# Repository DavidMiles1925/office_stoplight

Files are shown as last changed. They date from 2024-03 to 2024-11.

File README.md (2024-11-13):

# Office Stoplight

Stoplight GIF

## Project Decription

I work from home, and my workspace also happens to directly attatch to the garage. Because of this, my family often needs access to the garage, but does not know if I can be disturbed. This system will give them a definitive answer, by placing adjustable LEDs on the outside of the office and garage doors.

Please feel free to use everything here to build your own.

## Hardware

### Pre-requisites:

1. You will need to set up a Raspberry Pi. **[Click Here for Instructions](https://github.com/DavidMiles1925/pi_zero_setup)**

### Components List

NOTE: I used some larger LEDs for the "above door" unit, but that is optional.

| Item | Quantity | Link |
| --- | --- | --- |
| Raspberry Pi Zero | 1 | [Microcenter](https://www.microcenter.com/product/643085/raspberry-pi-zero-2-w) |
| Red LEDs | 2 | [Amazon](https://www.amazon.com/gp/product/B07QXR5MZB/ref=ppx_yo_dt_b_search_asin_title?ie=UTF8&psc=1) |
| Yellow LEDs | 2 | [Amazon](https://www.amazon.com/gp/product/B07QXR5MZB/ref=ppx_yo_dt_b_search_asin_title?ie=UTF8&psc=1) |
| Green LEDs | 2 | [Amazon](https://www.amazon.com/gp/product/B07QXR5MZB/ref=ppx_yo_dt_b_search_asin_title?ie=UTF8&psc=1) |
| BLue LED | 1 | [Amazon](https://www.amazon.com/gp/product/B07QXR5MZB/ref=ppx_yo_dt_b_search_asin_title?ie=UTF8&psc=1) |
| 1KΩ Resistors | 3 | [Amazon](https://www.amazon.com/gp/product/B07ZX2CB6B/ref=ppx_yo_dt_b_search_asin_title?ie=UTF8&psc=1) |
| 220Ω Resistors | 2 | [Amazon](https://www.amazon.com/gp/product/B07ZX2CB6B/ref=ppx_yo_dt_b_search_asin_title?ie=UTF8&psc=1) |
| 147Ω Resistors | 6 | [Amazon](https://www.amazon.com/gp/product/B07ZX2CB6B/ref=ppx_yo_dt_b_search_asin_title?ie=UTF8&psc=1) |
| 12mm Colored Buttons | 3 | [Amazon](https://www.amazon.com/gp/product/B075VBV4QH/ref=ppx_yo_dt_b_search_asin_title?ie=UTF8&psc=1) |
| Two-Prong Button | 1 | [Amazon](https://www.amazon.com/gp/product/B0827LX3FV/ref=ppx_yo_dt_b_search_asin_title?ie=UTF8&psc=1) |
| Wire | 25ft | [Amazon](https://www.amazon.com/gp/product/B0CFJY34GD/ref=ppx_yo_dt_b_search_asin_title?ie=UTF8&th=1)  |

### Circuit Diagram

This diagram represents the circuit for the "desk" unit. For the "door" unit, simply omit the buttons.

Use the table in the [Connections](#connections) section to connect the pins to the Pi's pins.

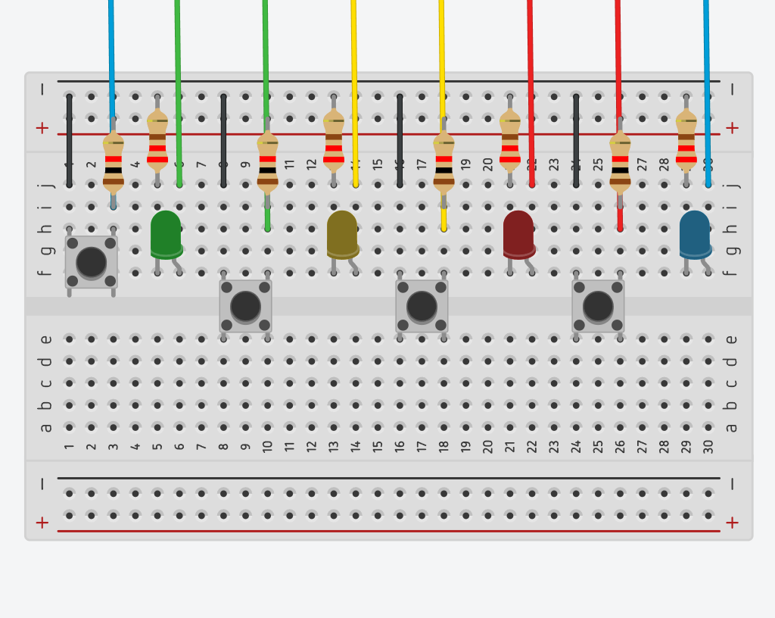
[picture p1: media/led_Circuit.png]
Diagram


### Resistor Values

**Value for buttons:** 1KΩ

**Value for Green and Yellow LEDs:** 147Ω

**Value for Red LEDs:** 220Ω

### Connections

| Purpose | Pin (BCM) |
| --- | --- |
| Power Indicator | 17 |
| Red LED - Desk | 5 |
| Red LED - Hall | 11 |
| Yellow LED - Desk | 6 |
| Yellow LED - Hall | 13 |
| Green LED - Desk | 26 |
| Green LED - Hall | 19 |
| Button - Lights OFF | 12 |
| Button - Red Light ON | 23 |
| Button - Yellow Light ON | 24 |
| Button - Green Light ON  | 25 |

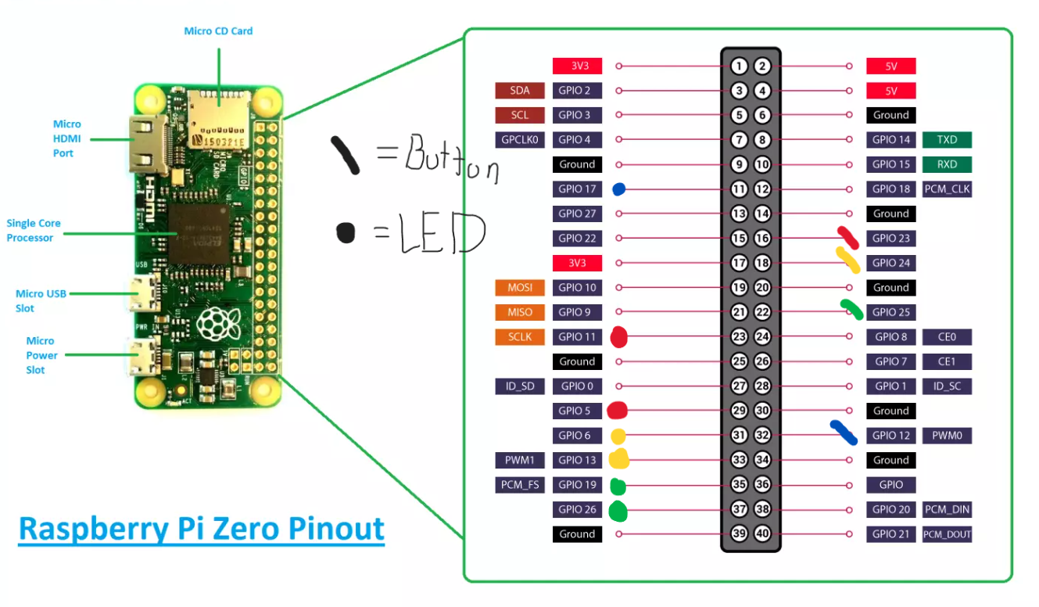
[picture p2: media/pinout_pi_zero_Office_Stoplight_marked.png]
Pi Diagram


## Running the Code

**1. Clone the Repo**

```bash
git clone https://github.com/DavidMiles1925/office_stoplight.git
```

**2. Navigate to Program Directory**

```bash
cd office_stoplight
```

**3. Test the program**

```bash
sudo python stoplight.py
```

**4. Set to Run on Startup**

```bash
sudo nano /etc/rc.local
```

**Add this to the file `rc.local`. _DO NOT FORGET THE "&"_**

```bash
sudo python /your_pi_name/office_stoplight/stoplight.py &
```

## What the Lights Mean

- **RED:** DO NOT DISTURB
- **YELLOW:** You can come in, but be quiet.
- **GREEN:** Come on in!

## Description and Gallery

**Prototying**

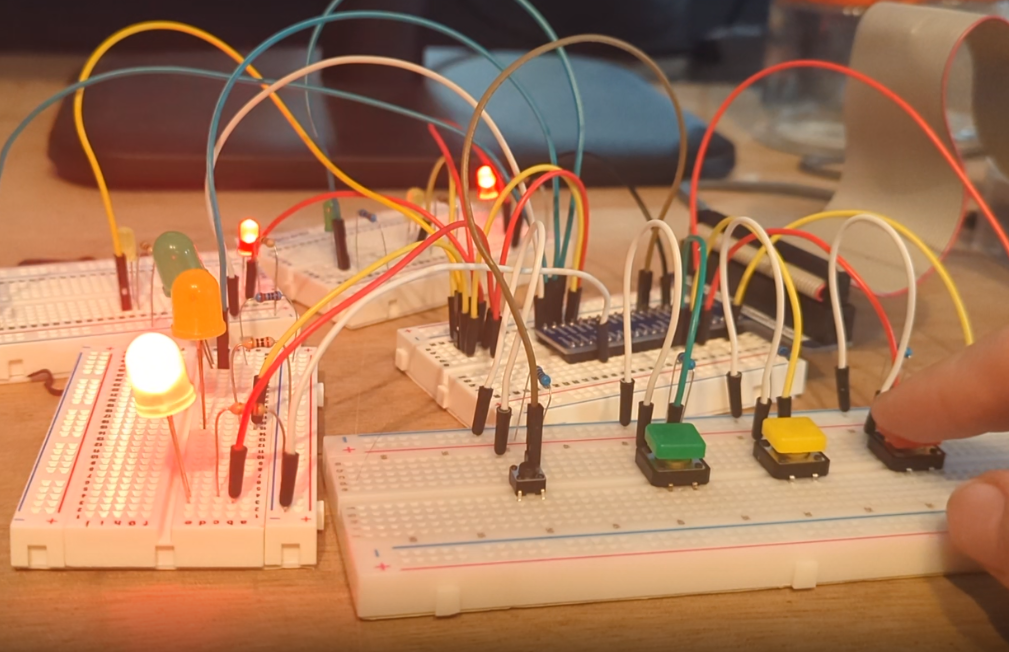
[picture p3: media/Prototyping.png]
Prototype

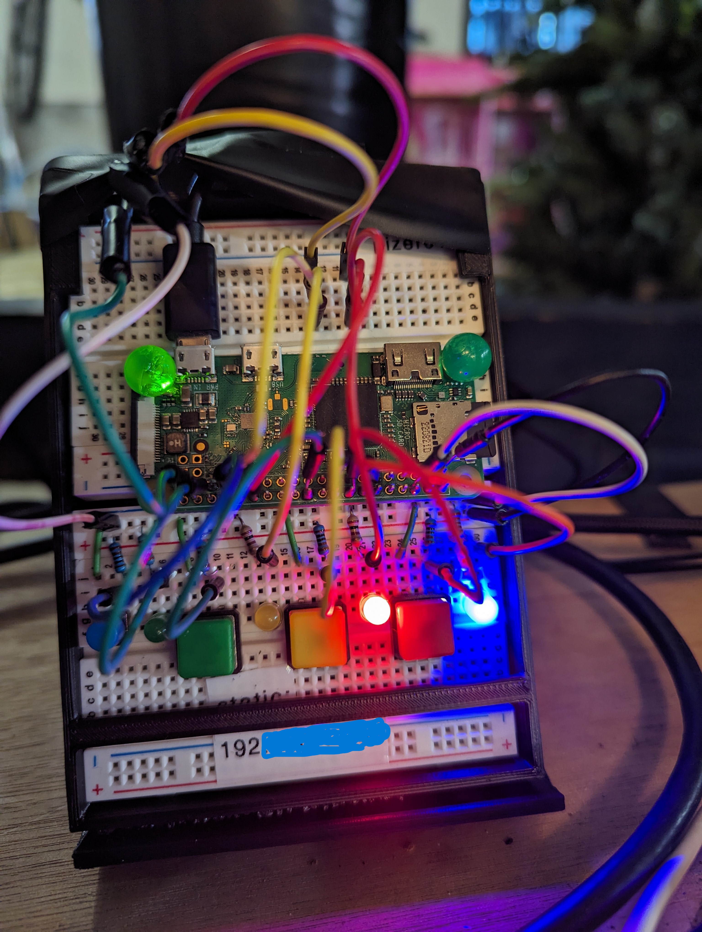
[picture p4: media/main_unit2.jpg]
Open


**Main Unit - Final**

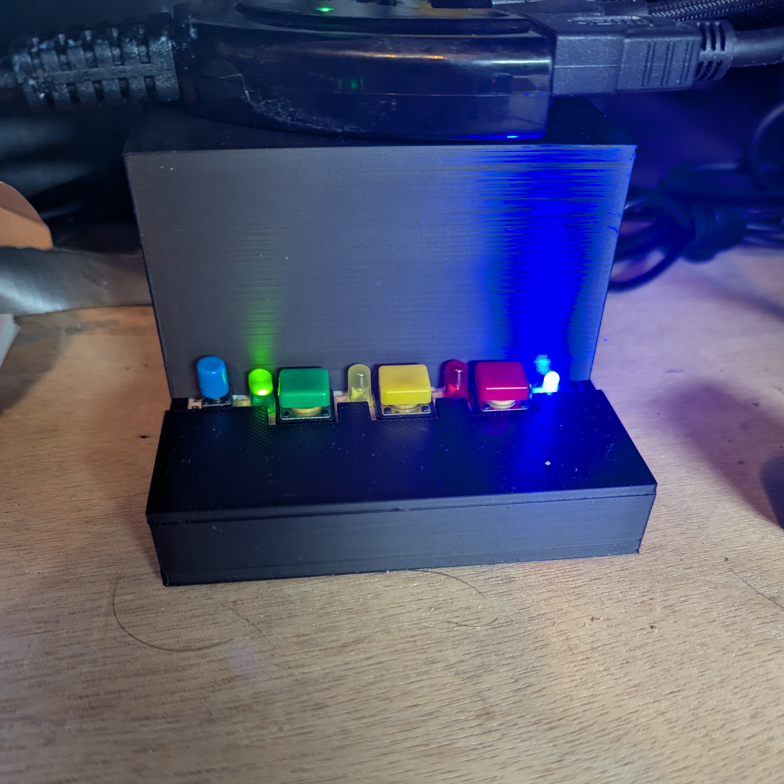
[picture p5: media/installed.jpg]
Main Unit


**Door Unit - Final**

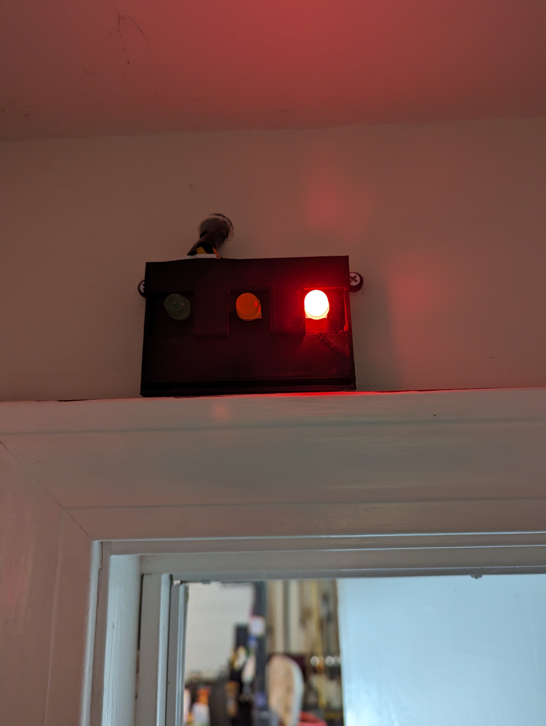
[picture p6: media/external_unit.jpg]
Door Unit


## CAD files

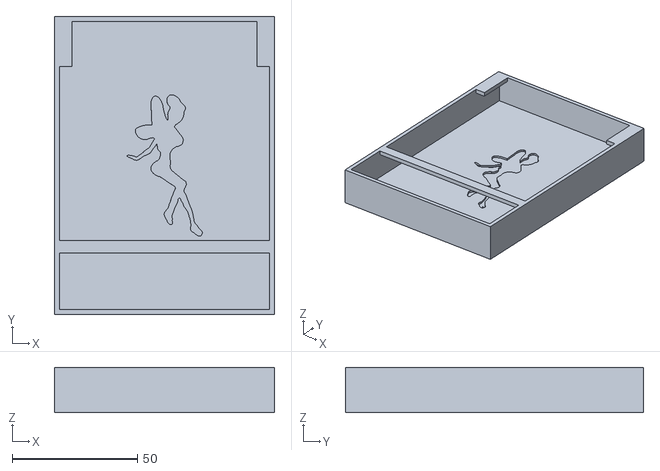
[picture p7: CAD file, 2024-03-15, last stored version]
3D Printable Models/Breadboard Holder for Main Unit.stl
88.0 x 119.0 x 18.0

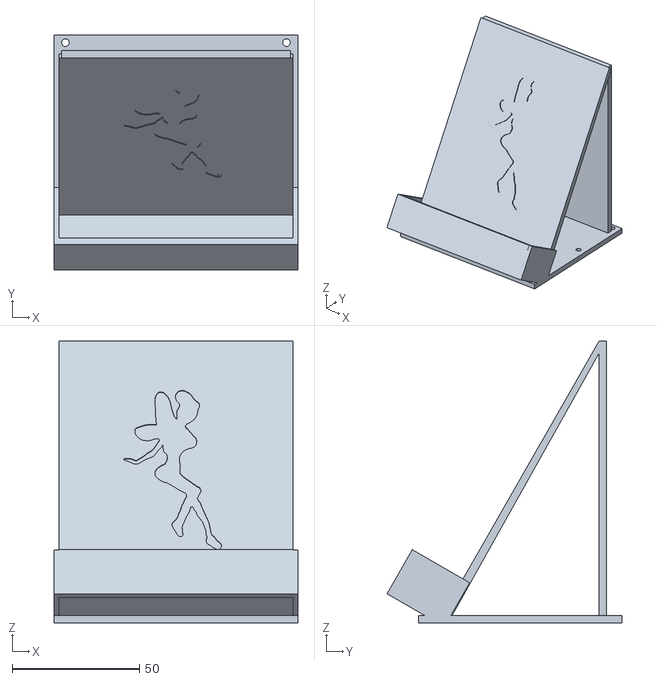
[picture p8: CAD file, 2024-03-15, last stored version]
3D Printable Models/Main Unit Stand.stl
96.0 x 92.5 x 111.0

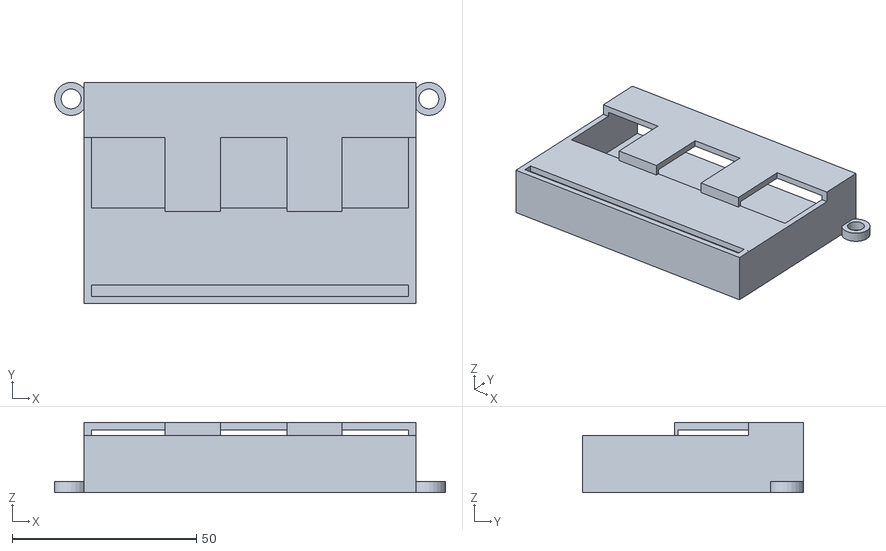
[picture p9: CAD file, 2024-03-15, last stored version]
3D Printable Models/External LED Holder.stl
106.0 x 60.0 x 19.0

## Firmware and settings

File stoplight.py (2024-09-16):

import RPi.GPIO as GPIO
from time import sleep

INDICATOR_LED_PIN = 17

RED1_LED_PIN = 5
RED2_LED_PIN = 11
YELLOW1_LED_PIN = 6
YELLOW2_LED_PIN = 13
GREEN1_LED_PIN = 26
GREEN2_LED_PIN = 19

BLUE_BUTTON_PIN = 12
RED_BUTTON_PIN = 23
YELLOW_BUTTON_PIN = 24
GREEN_BUTTON_PIN = 25

LED_PIN_ARRAY = [INDICATOR_LED_PIN, RED1_LED_PIN, RED2_LED_PIN, YELLOW1_LED_PIN, YELLOW2_LED_PIN, GREEN1_LED_PIN, GREEN2_LED_PIN]
BUTTON_PIN_ARRAY = [BLUE_BUTTON_PIN, RED_BUTTON_PIN, YELLOW_BUTTON_PIN, GREEN_BUTTON_PIN]

# This functions turns ALL LEDs "ON" or "OFF" depending on the status parameter

def all_leds(status):

    if status == "on" or status == "ON":
        for x in range(len(LED_PIN_ARRAY)):
            GPIO.output(LED_PIN_ARRAY[x], GPIO.HIGH)

    else:
        for x in range(len(LED_PIN_ARRAY)):
            GPIO.output(LED_PIN_ARRAY[x], GPIO.LOW)

    GPIO.output(INDICATOR_LED_PIN, GPIO.HIGH)



def led_on(pin):
    GPIO.output(pin, GPIO.HIGH)


def setup_pins():
    # Board Mode: BCM
    GPIO.setmode(GPIO.BCM)

    # Disable Warnings
    GPIO.setwarnings(False)

    for x in range(len(LED_PIN_ARRAY)):
        GPIO.setup(LED_PIN_ARRAY[x], GPIO.OUT)
        GPIO.output(LED_PIN_ARRAY[x], GPIO.LOW)
        print(f"Pin {LED_PIN_ARRAY[x]} enabled as output")

    for x in range(len(BUTTON_PIN_ARRAY)):
        GPIO.setup(BUTTON_PIN_ARRAY[x], GPIO.IN)
        print(f"Pin {BUTTON_PIN_ARRAY[x]} enabled as input")


def handle_error(e, msg):
    print(msg)
    print(f"Error: {e}")
    GPIO.cleanup()
    exit()


def check_buttons():
    try:
        if GPIO.input(RED_BUTTON_PIN) == False and GPIO.input(YELLOW_BUTTON_PIN) == False:
            light_show()


        if GPIO.input(BLUE_BUTTON_PIN) == False and GPIO.input(RED_BUTTON_PIN) == False:
            print("Blue and Red Buttons Pressed. Program Terminated.")
            print("DONE")
            GPIO.cleanup()
            exit()

            
        if GPIO.input(BLUE_BUTTON_PIN) == False:
            all_leds("off")
            print("OFF")
            sleep(0.2)

        elif GPIO.input(RED_BUTTON_PIN) == False:
            print("RED")
            all_leds("off")
            led_on(RED1_LED_PIN)
            led_on(RED2_LED_PIN)
            sleep(0.2)

        elif GPIO.input(YELLOW_BUTTON_PIN) == False:
            print("YELLOW")
            all_leds("off")
            led_on(YELLOW1_LED_PIN)
            led_on(YELLOW2_LED_PIN)
            sleep(0.2)

        elif GPIO.input(GREEN_BUTTON_PIN) == False:
            print(f"GREEN")
            all_leds("off")
            led_on(GREEN1_LED_PIN)
            led_on(GREEN2_LED_PIN)
            sleep(0.2)

    except Exception as e:
        handle_error(e, "The check_buttons function failed")


def light_show():
    try:
        print("Light show!")

        # lightshow_on = True
        lightshow_on = 0
        loop_sleep_time = 0.1

        all_leds("on")
        sleep(0.5)
        all_leds("off")

        while lightshow_on < 7:

            all_leds("off")
            led_on(RED1_LED_PIN)
            led_on(RED2_LED_PIN)
            sleep(loop_sleep_time)

            all_leds("off")
            led_on(YELLOW1_LED_PIN)
            led_on(YELLOW2_LED_PIN)
            sleep(loop_sleep_time)

            all_leds("off")
            led_on(GREEN1_LED_PIN)
            led_on(GREEN2_LED_PIN)
            sleep(loop_sleep_time)

            lightshow_on = lightshow_on + 1

        all_leds("off")
        led_on(RED1_LED_PIN)
        led_on(RED2_LED_PIN)

    except Exception as e:
        handle_error(e, "The light_show function failed")
    


if __name__ == "__main__":
    setup_pins()

    GPIO.output(INDICATOR_LED_PIN, GPIO.HIGH)

    light_show()

    try:
        while True:
            check_buttons()

    except Exception as e:
        handle_error(e, "The main function failed")

    except KeyboardInterrupt:
        print("Ctrl+C pressed. Program Terminated")
        GPIO.cleanup()
        exit()


        

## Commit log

2023-11-10 switch pins for zero port
2024-03-15 refactor and update readme
    [External LED Holder.stl, Main Unit Stand.stl]
2024-03-15 add 3d model
    [Breadboard Holder for Main Unit.stl]
2024-03-19 add second LED for yellow and red
2024-03-19 fix: indicator light turning off
    [stoplight.py]
2024-11-04 readme: begin competition updates
    [Breadboard Holder for Main Unit.stl, External LED Holder.stl, Main Unit Stand.stl]
